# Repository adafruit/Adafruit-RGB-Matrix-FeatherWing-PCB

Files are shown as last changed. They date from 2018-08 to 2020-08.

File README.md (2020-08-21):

## Adafruit RGB Matrix Featherwing Kit PCB - For M0 and M4 Feathers
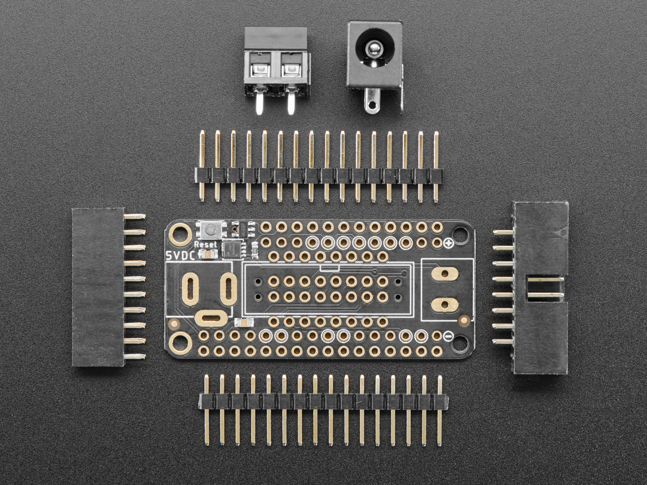
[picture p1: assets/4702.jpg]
<br/>
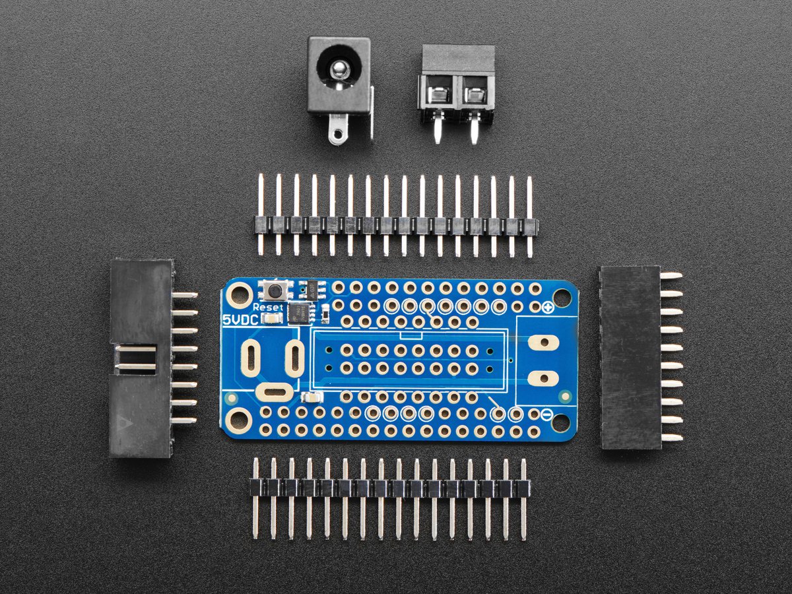
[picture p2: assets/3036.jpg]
<a href="http://www.adafruit.com/products/3036"><br/>
Click here to purchase one from the Adafruit shop</a>

PCB files for the Adafruit RGB Matrix Featherwing Kit. Format is EagleCAD schematic and board layout
* https://www.adafruit.com/product/3036

### Description

Ahoy! It's time to create a dazzling light up project with our new RGB Matrix FeatherWing. Now you can quickly and easily create projects featuring your favorite 16 or 32-pixel tall matrix boards. Using our RGB Matrix library is easy and works wonderfully with any of our M0, M4 or nRF52840 Feathers.

Please note: This wing is only tested/designed to work with the SAMD21 M0, SAMD51 M4 and nRF52840 Feathers. It's not for use with any other Feathers at this time. (That said, if you'd like to add support, [we'd be happy to take a pull request](https://github.com/adafruit/RGB-matrix-Panel) on the library repo)

This wing can be assembled in one of two ways. You can either solder in a 2x8 IDC shrouded header on the top, then plug in the IDC cable that came with your matrix. This makes it easy to stack on top of your Feather. Or, you can solder in the 2x10 socket header on the bottom of the Wing, and then stack your Feather on top. That way you can plug it directly into the back of the matrix *mind blown*

This FeatherWing will work great with any of our [16x32](https://www.adafruit.com/?q=16x32), [32x32](https://www.adafruit.com/?q=32x32) or [64x32](https://www.adafruit.com/?q=64x32) RGB matrices, and is definitely the easiest way to glow and go.

Either way you decide to go, you can plug a 5V DC power pack into the 2.1mm DC jack. That 5V is polarity protected and then output on the other side to a 5.08mm terminal block. An onboard regulator will provide 3.3V power to your Feather so you don't need a separate USB or battery, this makes for a very compact build!

### License

Adafruit invests time and resources providing this open source design, please support Adafruit and open-source hardware by purchasing products from [Adafruit](https://www.adafruit.com)!

Designed by Limor Fried/Ladyada for Adafruit Industries.

Creative Commons Attribution/Share-Alike, all text above must be included in any redistribution. See license.txt for additional details.

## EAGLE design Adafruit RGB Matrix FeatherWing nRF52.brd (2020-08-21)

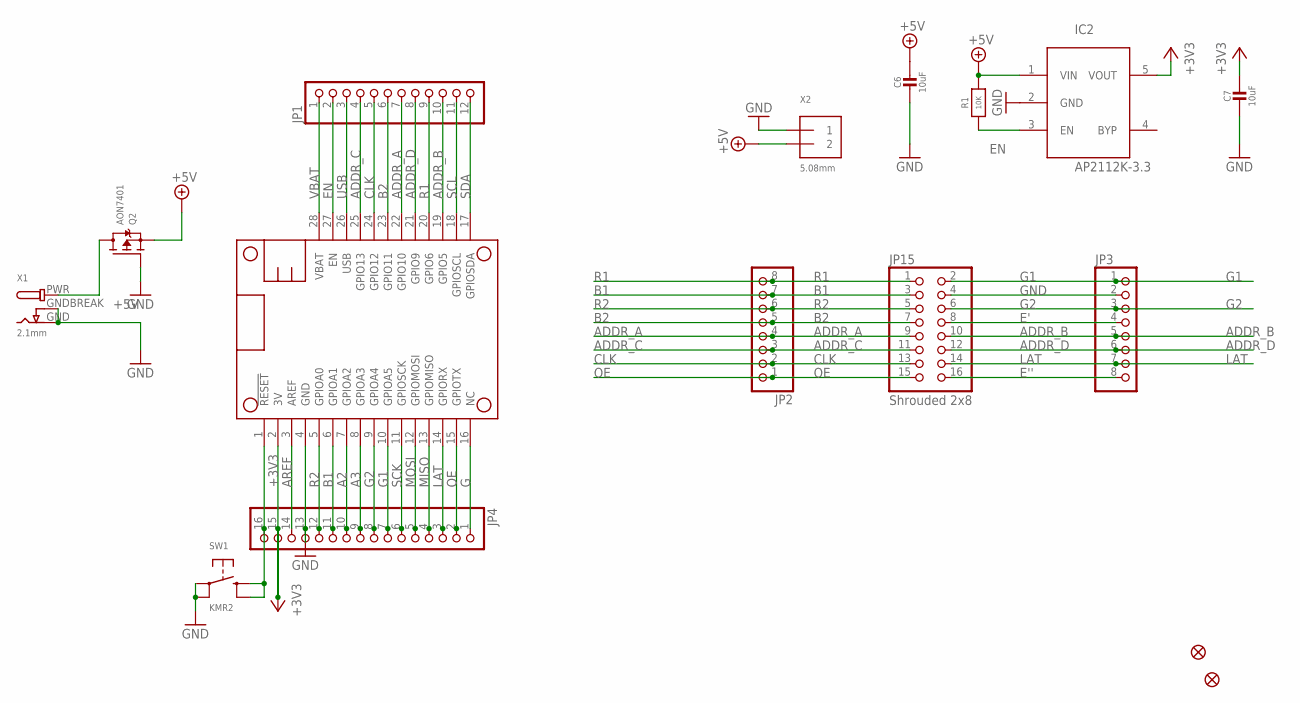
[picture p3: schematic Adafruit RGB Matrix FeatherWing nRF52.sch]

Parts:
C6, C7: 10uF; 0805-NO
FID1, FID3: FIDUCIAL_1MM
IC2: AP2112K-3.3; SOT23-5L
JP1: HEADER-1X12; 1X12_ROUND
JP2, JP3: HEADER-1X870MIL; 1X08_ROUND_70
JP4: HEADER-1X16ROUND; 1X16_ROUND
JP15: Shrouded 2x8; 2X08_SHROUDED
MS1: FEATHERWING
Q2: AON7401; POWERDI3333
R1: 10K; 0603-NO
SW1: KMR2; BTN_KMR2_4.6X2.8
X1: 2.1mm; DCJACK_2MM_PTH
X2: 5.08mm; TERMBLOCK_508_1X2

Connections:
+3V3: C7.1, IC2.5 (VOUT), JP4.15, MS1.2 (3V)
+5V: C6.1, IC2.1 (VIN), Q2.1 (S), Q2.2 (S), Q2.3 (S), R1.2, X2.P$4 (2)
A2: JP4.10, MS1.7 (GPIOA2)
A3: JP4.9, MS1.8 (GPIOA3)
ADDR_A: JP1.7, JP2.4, JP15.9, MS1.22 (GPIO10)
ADDR_B: JP1.10, JP3.5, JP15.10, MS1.19 (GPIO5)
ADDR_C: JP1.4, JP2.3, JP15.11, MS1.25 (GPIO13)
ADDR_D: JP1.8, JP3.6, JP15.12, MS1.21 (GPIO9)
AREF: JP4.14, MS1.3 (AREF)
B1: JP2.7, JP4.11, JP15.3, MS1.6 (GPIOA1)
B2: JP1.6, JP2.5, JP15.7, MS1.23 (GPIO11)
CLK: JP1.5, JP2.2, JP15.13, MS1.24 (GPIO12)
E': JP3.4, JP15.8
E'': JP3.8, JP15.16
EN: IC2.3 (EN), JP1.2, MS1.27 (EN), R1.1
G: JP4.1, MS1.16 (NC)
G1: JP3.1, JP4.7, JP15.2, MS1.10 (GPIOA5)
G2: JP3.3, JP4.8, JP15.6, MS1.9 (GPIOA4)
GND: C6.2, C7.2, IC2.2 (GND), JP3.2, JP4.13, JP15.4, MS1.4 (GND), Q2.4 (G), SW1.A, SW1.A' (P1), X1.GND, X1.GNDBREAK, X2.P$3 (1)
LAT: JP3.7, JP4.3, JP15.14, MS1.14 (GPIORX)
MISO: JP4.4, MS1.13 (GPIOMISO)
MOSI: JP4.5, MS1.12 (GPIOMOSI)
OE: JP2.1, JP4.2, JP15.15, MS1.15 (GPIOTX)
R1: JP1.9, JP2.8, JP15.1, MS1.20 (GPIO6)
R2: JP2.6, JP4.12, JP15.5, MS1.5 (GPIOA0)
RESET: JP4.16, MS1.1 (!RESET), SW1.B (S), SW1.B' (S1)
SCK: JP4.6, MS1.11 (GPIOSCK)
SCL: JP1.11, MS1.18 (GPIOSCL)
SDA: JP1.12, MS1.17 (GPIOSDA)
USB: JP1.3, MS1.26 (USB)
VBAT: JP1.1, MS1.28 (VBAT)
VIN: Q2.5678 (D), X1.PWR

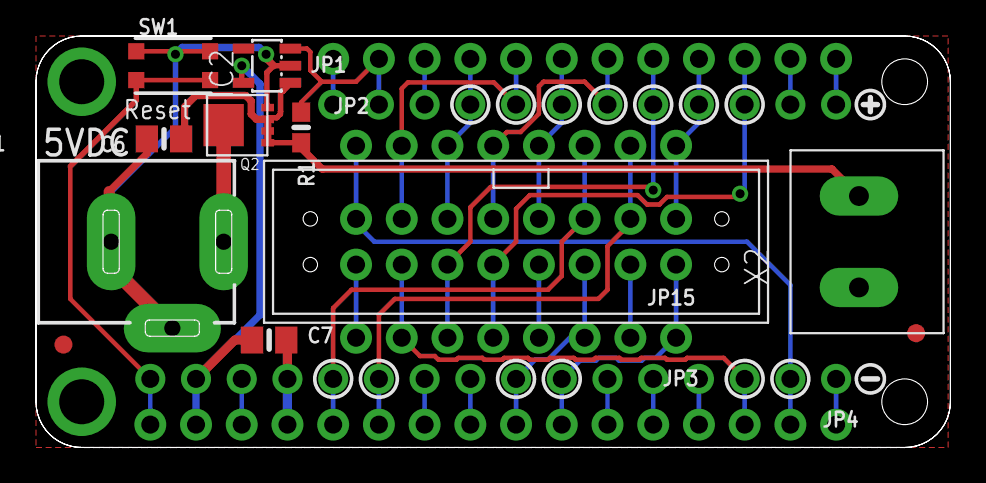
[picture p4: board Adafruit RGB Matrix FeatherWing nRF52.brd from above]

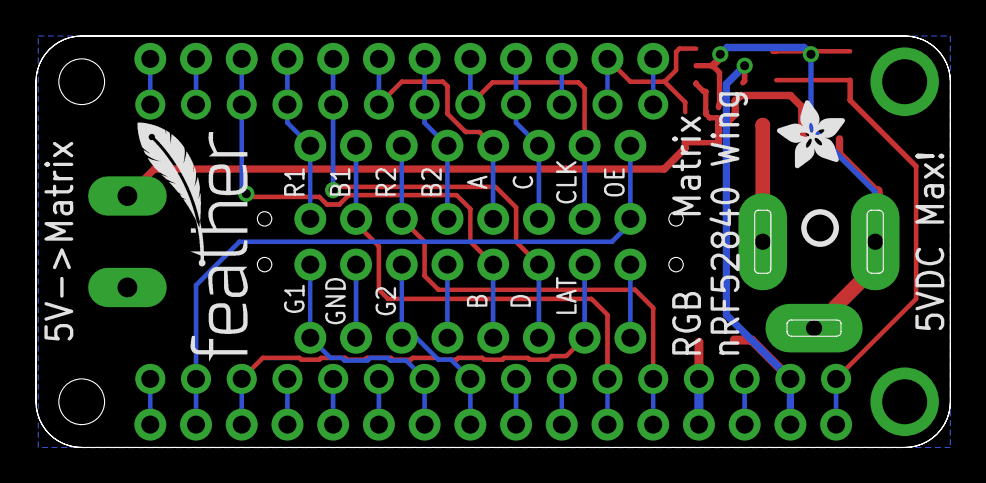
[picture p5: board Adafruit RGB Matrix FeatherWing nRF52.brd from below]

Board: 2 copper layers, 50.8 x 22.9 mm, 21 parts (3 on the bottom side), 32 nets.

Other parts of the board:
U$1: SYMBOL_PLUS
U$2: PCBFEAT-REV-040
U$3: FEATHERLOGO_SMALL
U$6: SYMBOL_MINUS
U$7: ADAFRUIT_3.5MM

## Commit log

2019-07-16 updating to use pcb page cookiecutter
2020-08-21 Add nRF board files.
    [Adafruit RGB Matrix FeatherWing nRF52.brd, Adafruit RGB Matrix FeatherWing nRF52.sch]
